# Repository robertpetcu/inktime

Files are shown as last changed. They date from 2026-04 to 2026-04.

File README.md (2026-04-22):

# InkTime - TSC

## Robert Cristian Petcu

# InkTime Smartwatch

InkTime is a smartwatch prototype built around the **nRF52840** SoC. The device features an **E-Paper display**, **BLE connectivity**, **battery charging and monitoring**, **motion sensing**, and **haptic feedback**, all integrated into a compact low-power wearable platform. The system is designed around a Li-Po battery, USB-C charging, an efficient 3.3V power stage, and a modular peripheral architecture.

---

## 1. Block Diagram

```text
+----------------------+
|      USB-C Port      |
+----------+-----------+
           |
           v
+----------------------+
|  Power / Charging IC |
|     BQ25180YBGR      |
+----------+-----------+
           |
           v
+----------------------+          +----------------------+
|    Li-Po Battery     |--------->|    3V3 Regulator    |
+----------------------+   VBAT   |      RT6160AWSC     |
                                  +----------+-----------+
                                             |
                                             v
                                   +----------------------+
                                   |     nRF52840 MCU     |
                                   |      MCU + BLE       |
                                   +---+----+----+---+----+
                                       |    |    |   |
                 USB ------------------+    |    |   +---------------- GPIO
                                       |    |    |                       |
                                       |    |    |                       +--> Buttons
                                       |    |    |
                                       |    |    +---------------- SWD
                                       |    |                            |
                                       |    |                            +--> SWD Debug
                                       |    |
                                       |    +---------------- I2C
                                       |                                 |
                                       |                                 +--> IMU (BMA421)
                                       |                                 |
                                       |                                 +--> Fuel Gauge (MAX17048G+T10)
                                       |                                 |
                                       |                                 +--> Haptic Driver (DRV2605YZFR)
                                       |                                                       |
                                       |                                                       +--> Haptic Motor
                                       |
                     SPI --------------+------------------------> E-Paper Display
                                       |                         (Display + E-Paper Drive)
                                       |
                     RF ---------------+------------------------> 2.4 GHz Antenna
                                                                 2450AT18B100E
                                                                
```

---

## 2. Bill of Materials (BOM)

### 2.1 Main Components

| Component | Designator(s) | Qty | Package | Purpose | JLC Parts | Datasheet |
|---|---|---:|---|---|---|---|
| nRF52840 | U1 | 1 | aQFN | Main MCU + BLE | [JLC Search](https://jlcpcb.com/parts/componentSearch?searchTxt=nRF52840) | [Nordic Product Page](https://www.nordicsemi.com/Products/nRF52840) |
| BQ25180YBGR | IC1 | 1 | BGA | Li-Po charging / power path | [JLC Search](https://jlcpcb.com/parts/componentSearch?searchTxt=BQ25180YBGR) | [TI Product Page](https://www.ti.com/product/BQ25180) |
| RT6160AWSC | IC9 | 1 | BGA | 3V3 regulator / DC-DC | [JLC Search](https://jlcpcb.com/parts/componentSearch?searchTxt=RT6160AWSC) | [Richtek Product Page](https://www.richtek.com/m/Products/Switching%20Regulators/Buck-Boost%20Converter/RT6160A?sc_lang=en) |
| BMA421 | IC3 | 1 | LGA | IMU sensor | [JLC Search](https://jlcpcb.com/parts/componentSearch?searchTxt=BMA421) | [Datasheet PDF](https://files.pine64.org/doc/datasheet/pinetime/BST-BMA421-FL000.pdf) |
| MAX17048G+T10 | U3 | 1 | SON / DFN | Fuel gauge | [JLC Search](https://jlcpcb.com/parts/componentSearch?searchTxt=MAX17048G%2BT10) | [Analog Devices Product Page](https://www.analog.com/en/products/max17048.html) |
| DRV2605YZFR | IC2 | 1 | DSBGA | Haptic driver | [JLC Search](https://jlcpcb.com/parts/componentSearch?searchTxt=DRV2605YZFR) | [TI Product Page](https://www.ti.com/product/DRV2605) |
| KH-TYPE-C-16P | J4 | 1 | SMD | USB-C connector | [JLC Search](https://jlcpcb.com/parts/componentSearch?searchTxt=KH-TYPE-C-16P) | [Datasheet PDF](https://datasheet.lcsc.com/lcsc/2404191039_Shenzhen-Kinghelm-Elec-KH-TYPE-C-16P_C709357.pdf) |
| 503480-2400 | J1 | 1 | FPC | E-paper display connector | [JLC Search](https://jlcpcb.com/parts/componentSearch?searchTxt=503480-2400) | [Molex Product Page](https://www.molex.com/en-us/products/part-detail/5034802400) |
| TC2030-IDC | J2 | 1 | Debug connector | SWD programming / debug | [JLC Search](https://jlcpcb.com/parts/componentSearch?searchTxt=TC2030-IDC) | [Tag-Connect Product Page](https://www.tag-connect.com/product/tc2030-idc-6-pin-tag-connect-plug-of-nails-spring-pin-cable-with-legs) |
| 2450AT18B100E | ANT1 | 1 | SMD antenna | 2.4 GHz antenna | [JLC Search](https://jlcpcb.com/parts/componentSearch?searchTxt=2450AT18B100E) | [Johanson Datasheet PDF](https://www.johansontechnology.com/docs/1187/2450AT18B100_X8XXogU.pdf) |
| 32 MHz crystal | X1 | 1 | 2016 | Main high-speed clock | [JLC Search](https://jlcpcb.com/parts/componentSearch?searchTxt=32MHz%202016) | [Search / vendor selection](https://jlcpcb.com/parts/componentSearch?searchTxt=32MHz%202016%20crystal) |
| 32.768 kHz crystal | X2 | 1 | 3215 | Low-power RTC clock | [JLC Search](https://jlcpcb.com/parts/componentSearch?searchTxt=32.768kHz%203215) | [Search / vendor selection](https://jlcpcb.com/parts/componentSearch?searchTxt=32.768kHz%203215%20crystal) |
| Buttons | SW_UP, SW_ENT, SW_DN | 3 | SMD | User input | [JLC Search](https://jlcpcb.com/parts/componentSearch?searchTxt=EVP-AKE31A) | [Panasonic Search](https://industry.panasonic.com/global/en/search?keyword=EVP-AKE31A) |
| USB ESD protection | D3 | 1 | SOT-23-6 | USB line protection | [JLC Search](https://jlcpcb.com/parts/componentSearch?searchTxt=USBLC6-2SC6Y) | [ST Product Page](https://www.st.com/en/protections-and-emi-filters/usblc6-2sc6y.html) |
| Schottky diodes | D2, D4, D5 | 3 | SMD | E-paper drive circuit | [JLC Search](https://jlcpcb.com/parts/componentSearch?searchTxt=MBR0530) | [onsemi Datasheet PDF](https://www.onsemi.com/download/data-sheet/pdf/mbr0530t1-d.pdf) |

---

## 3. Hardware Functionality Description

The InkTime smartwatch is built around the **nRF52840**, which acts as the main MCU and BLE controller. It manages the display, sensors, battery monitoring, haptic feedback, buttons, debugging, and RF communication.

### 3.1 Main MCU - nRF52840
The **nRF52840** is the central controller of the system. It was chosen for its:
- low power consumption
- BLE support
- SPI, I2C, USB, and SWD interfaces
- enough GPIOs for all peripherals

### 3.2 Power and Charging
The device is powered by a **Li-Po battery** and charged through **USB-C**. Charging and power-path management are handled by the **BQ25180YBGR**, while the **RT6160AWSC** generates the regulated **3.3V** supply for the system.

### 3.3 E-Paper Display
The display is connected through an **FPC connector** and controlled by the MCU over **SPI**. The display subsystem includes both the connector and the dedicated **e-paper drive circuit**.

### 3.4 IMU
Motion sensing is provided by the **BMA421**, connected over **I2C**. It is used for motion detection, gesture handling, and wake-up events.

### 3.5 Fuel Gauge
Battery monitoring is handled by the **MAX17048G+T10**, connected over **I2C**. It provides battery voltage and state-of-charge information to the MCU.

### 3.6 Haptic Driver
Haptic feedback is implemented using the **DRV2605YZFR**, also connected through **I2C**. It drives the vibration motor for notifications and user feedback.

### 3.7 Buttons
The device includes three buttons:
- **SW_UP**
- **SW_ENT**
- **SW_DN**

These are connected to GPIO pins and are used for user input and menu navigation.

### 3.8 SWD Debug
Programming and debugging are done through the **TC2030-IDC** SWD interface, which provides access to flashing and debugging during development.

### 3.9 RF Section
Wireless communication is handled by the nRF52840 through the **2450AT18B100E** 2.4 GHz antenna and its RF matching network.

---

## 4. nRF52840 Pin Usage

| Function | nRF52840 Pin | Description |
|---|---|---|
| EPD_CS | P0.05 | E-paper chip select |
| SDA | P0.06 | I2C data line |
| SCL | P0.07 | I2C clock line |
| IMU_INT1 | P0.08 | IMU interrupt 1 |
| IMU_INT2 | P1.08 | IMU interrupt 2 |
| Fuel Gauge ALERT | P0.10 | Battery alert signal |
| PMIC_INT | P0.11 | Charger / PMIC interrupt |
| HAPTIC_EN | P0.12 | Haptic control / enable |
| SW_UP | P0.13 | Button input |
| SW_ENT | P0.14 | Button input |
| SW_DN | P1.02 | Button input |
| SWDIO | SWDIO | Debug data |
| SWDCLK | SWDCLK | Debug clock |
| RESET | P0.18 / RESET | System reset |
| USB D+ / D- | Dedicated USB pins | USB interface |
| RF ANT | ANT | Antenna connection |

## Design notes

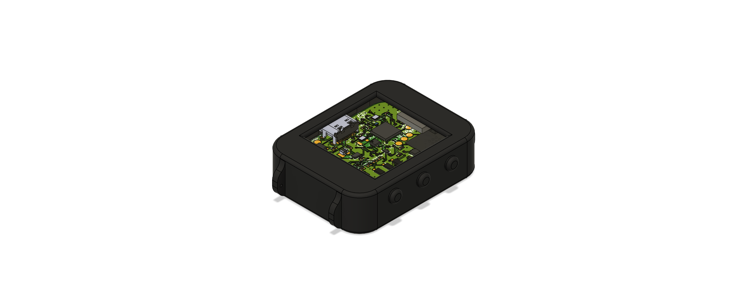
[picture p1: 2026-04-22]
Images/WearAwareNewCase.png

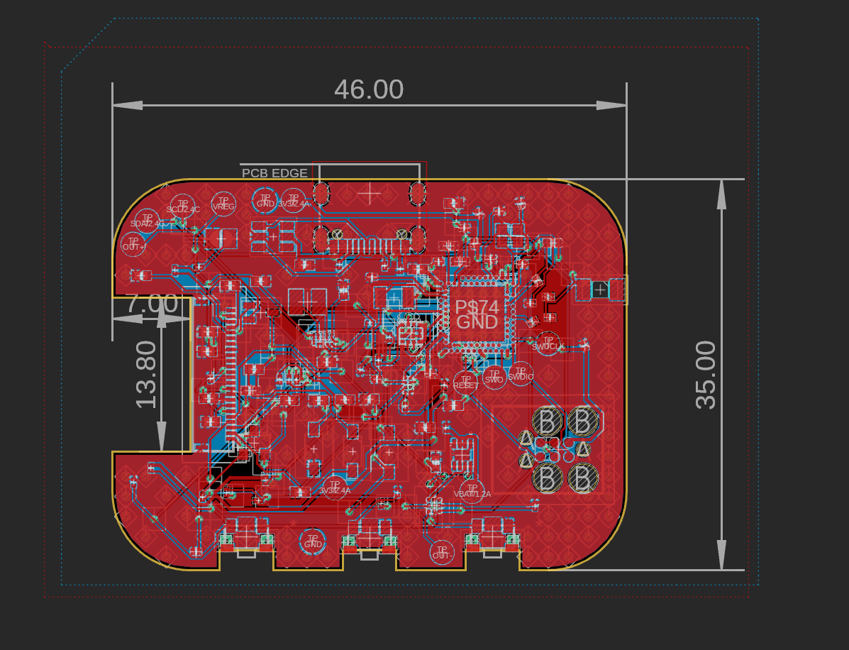
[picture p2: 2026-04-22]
Images/2dpcb.png

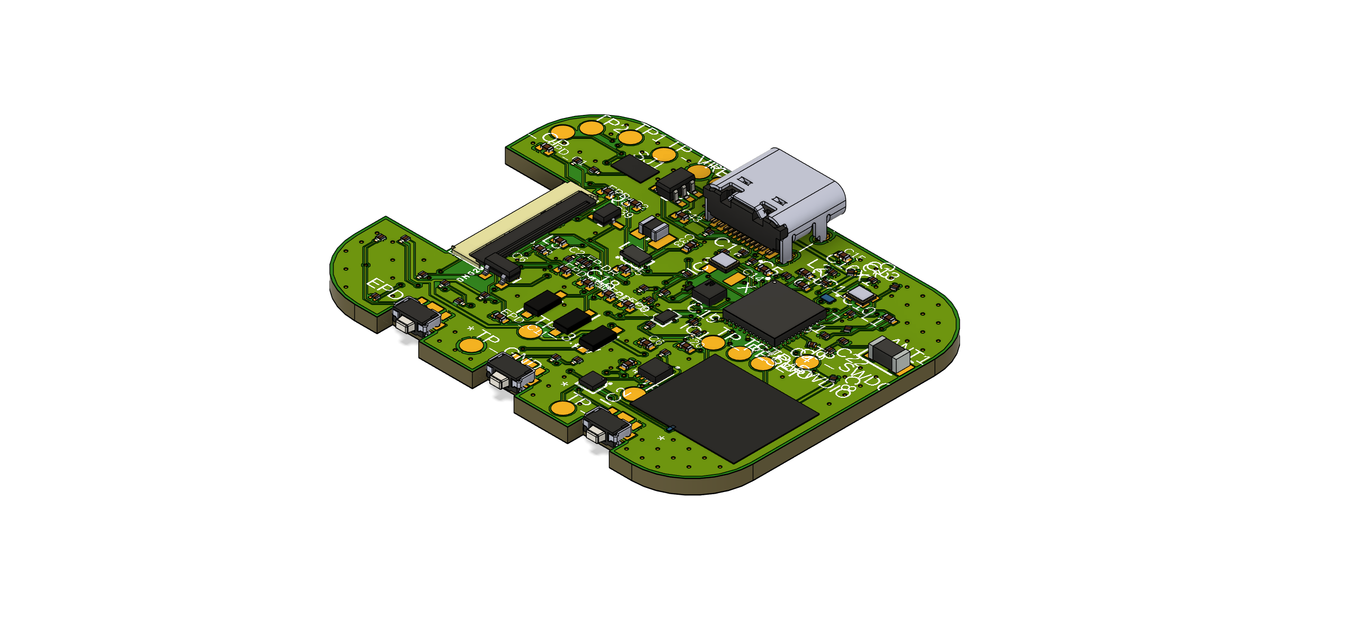
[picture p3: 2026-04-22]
Images/PCB3d.png

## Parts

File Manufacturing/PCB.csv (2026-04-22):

Qty | Value | Device | Package | Parts | Description | ARROW_PART_NUMBER | ARROW_PRICE-STOCK | AVAILABILITY | CHECK_PRICES | COPYRIGHT | DESCRIPTION | DIGI-KEY_PART_NUMBER_1 | DIGI-KEY_PART_NUMBER_2 | DIGI-KEY_PART_NUMBER_3 | HEIGHT | JLCPCB | MANUFACTURER_NAME | MANUFACTURER_PART_NUMBER | MF | MOUSER_PART_NUMBER | MOUSER_PRICE-STOCK | MP | PACKAGE | POPULARITY | PRICE | PROD_ID | PURCHASE-URL | SNAPEDA_LINK | TP_SIGNAL_NAME | VALUE
1 |  | ESP32_C6_LIBRARY_7_JUMPER_SJ | ESP32_C6_LIBRARY_7_JUMPER_SJ | SJ1 | SMD solder JUMPER |  |  |  |  |  |  |  |  |  |  |  |  |  |  |  |  |  |  | 3
3 | 0 | CPF0201D7K68C1_CPF0201D7K68C1 | CPF0201D7K68C1_0201 | R2, R3, R4 | 7.68k 0201 Thin Film Surface Mount Fixed Resistor +/-0.5% 0.031W CPF0201D7K68C1
4 | 0.1uF | GRM011R60J152KE01L_1_GRM011R60J152KE01L | GRM011R60J152KE01L_1_0201 | C23, C27, C34, C42 | Check availability
1 | 0.1uF/50V | NORDIC_NRF_3_CAPACITOR_0201_L | NORDIC_NRF_3_RESC0201_L | EPD_C5 | Generic chip capacitor
1 | 0.47 | CPF0201D7K68C1_CPF0201D7K68C1 | CPF0201D7K68C1_0201 | R1_EP_DR | 7.68k 0201 Thin Film Surface Mount Fixed Resistor +/-0.5% 0.031W CPF0201D7K68C1
1 | 1.0µF | PERFECT_0402_CAP_0402 | PERFECT_0402_0402 | C15 | 0402 (1005 Metric)
5 | 100nF | NORDIC_NRF_3_CAPACITOR_0201_L | NORDIC_NRF_3_RESC0201_L | C5, C7, C8, C12, C19 | Generic chip capacitor
1 | 100pF | NORDIC_NRF_3_CAPACITOR_0201_L | NORDIC_NRF_3_RESC0201_L | C11 | Generic chip capacitor
3 | 10K | CPF0201D7K68C1_CPF0201D7K68C1 | CPF0201D7K68C1_0201 | R2_EP_DR, R9, R_PWR_EPD | 7.68k 0201 Thin Film Surface Mount Fixed Resistor +/-0.5% 0.031W CPF0201D7K68C1
3 | 10k | CPF0201D7K68C1_CPF0201D7K68C1 | CPF0201D7K68C1_0201 | R5, R7, R8 | 7.68k 0201 Thin Film Surface Mount Fixed Resistor +/-0.5% 0.031W CPF0201D7K68C1
3 | 10uF | PERFECT_0402_CAP_0402 | PERFECT_0402_0402 | C1-EP-DR, C24, C39 | 0402 (1005 Metric)
1 | 10µH | NORDIC_NRF_2_INDUCTOR_0402_L | NORDIC_NRF_2_RESC0402_L | L2 | Generic chip inductor
4 | 12pF | NORDIC_NRF_3_CAPACITOR_0201_L | NORDIC_NRF_3_RESC0201_L | C1, C2, C17, C18 | Generic chip capacitor
1 | 15nH | NORDIC_NRF_2_INDUCTOR_0402_L | NORDIC_NRF_2_RESC0402_L | L3 | Generic chip inductor
2 | 1pF | NORDIC_NRF_3_CAPACITOR_0201_L | NORDIC_NRF_3_RESC0201_L | C3, C4 | Generic chip capacitor
6 | 1uF | GRM011R60J152KE01L_1_GRM011R60J152KE01L | GRM011R60J152KE01L_1_0201 | C29, C30, C31, C32, C37, C38 | Check availability
9 | 1uF/50V | PERFECT_0402_CAP_0402 | PERFECT_0402_0402 | EPD_C1, EPD_C2, EPD_C6, EPD_C7, EPD_C8, EPD_C9, EPD_C10, EPD_C11, EPD_C12 | 0402 (1005 Metric)
1 | 2.2 | CPF0201D7K68C1_CPF0201D7K68C1 | CPF0201D7K68C1_0201 | R_TYPE_SEL | 7.68k 0201 Thin Film Surface Mount Fixed Resistor +/-0.5% 0.031W CPF0201D7K68C1
3 | 2025-10-22_07-23-44_LIBRARY_EVP-AKE31ASW_EVP-AKE31A_PAN | 2025-10-22_07-23-44_LIBRARY_EVP-AKE31ASW_EVP-AKE31A_PAN | 2025-10-22_07-23-44_LIBRARY_SW_EVP-AKE31A_PAN | SW_DN, SW_ENT, SW_UP |  |  |  |  |  | Copyright (C) 2025 Ultra Librarian. All rights reserved. |  | P123437TR-ND | P123437CT-ND | P123437DKR-ND |  |  | Panasonic | EVP-AKE31A
1 | 20V/4.2A/52mO/1.4W | ESP32_C6_LIBRARY_4_ESP32_WROVER_SPARKFUN-DISCRETESEMI_MOSFET_PCH-DMG2305UX-7 | ESP32_C6_LIBRARY_4_ESP32_C6_LIBRARY_4_ESP32_C6_LIBRARY_4_ESP32_C6_LIBRARY_4_ESP32_WROVER_SPARKFUN-DISCRETESEMI_SOT23-3 | DMG2305UX-7 | P-channel MOSFETs |  |  |  |  |  |  |  |  |  |  |  |  |  |  |  |  |  |  |  |  | TRAN-14388 |  |  |  | 20V/4.2A/52mO/1.4W
2 | 22uF | PERFECT_0402_CAP_0402 | PERFECT_0402_0402 | C25, C33 | 0402 (1005 Metric)
1 | 2450AT18B100E | 2450AT18B100E_2450AT18B100E | 2450AT18B100E_ANTC3216X140N | ANT1 | Antennas 2.45GHz ANTENNA | 2450AT18B100E | https://www.arrow.com/en/products/2450at18b100e/johanson-dielectrics?utm_currency=USD&region=nac |  |  |  | Antennas 2.45GHz ANTENNA |  |  |  | 1.4mm |  | JOHANSON TECHNOLOGY | 2450AT18B100E |  | 609-2450AT18B100E | https://www.mouser.co.uk/ProductDetail/Johanson-Technology/2450AT18B100E?qs=yCnrNFeXz%252Bh5MFsFIXGZGA%3D%3D
1 | 3.9nH | NORDIC_NRF_2_INDUCTOR_0402_L | NORDIC_NRF_2_RESC0402_L | L1 | Generic chip inductor
1 | 32.768kHz | NORDIC_NRF_1_XTAL_32KHZ | NORDIC_NRF_1_XTAL_3215_N | X2
1 | 32MHz | NORDIC_NRF_XTAL_32MHZ | NORDIC_NRF_BT-XTAL_2016_N | X1
2 | 3K3 | CPF0201D7K68C1_CPF0201D7K68C1 | CPF0201D7K68C1_0201 | R17, R18 | 7.68k 0201 Thin Film Surface Mount Fixed Resistor +/-0.5% 0.031W CPF0201D7K68C1
1 | 4.7uF | PERFECT_0402_CAP_0402 | PERFECT_0402_0402 | C43 | 0402 (1005 Metric)
1 | 4.7uF/25V | PERFECT_0402_CAP_0402 | PERFECT_0402_0402 | C2-EP-DR | 0402 (1005 Metric)
4 | 4.7µF | PERFECT_0402_CAP_0402 | PERFECT_0402_0402 | C6, C14, C20, C21 | 0402 (1005 Metric)
1 | 47nF | NORDIC_NRF_3_CAPACITOR_0201_L | NORDIC_NRF_3_RESC0201_L | C16 | Generic chip capacitor
1 | 503480-2400 | 503480-2400_503480-2400 | 503480-2400_5034802400 | J1 | FFC & FPC Connectors 0.5mm FPC RA SMT Dual Contact 24Ckt |  |  |  |  |  | FFC & FPC Connectors 0.5mm FPC RA SMT Dual Contact 24Ckt |  |  |  | 1.87mm |  | Molex | 503480-2400 |  | 538-503480-2400 | https://www.mouser.co.uk/ProductDetail/Molex/503480-2400?qs=OAhjpuo3Vu7efIoxFh9AOw%3D%3D
2 | 5K1 | CPF0201D7K68C1_CPF0201D7K68C1 | CPF0201D7K68C1_0201 | R1_USB, R2_USB | 7.68k 0201 Thin Film Surface Mount Fixed Resistor +/-0.5% 0.031W CPF0201D7K68C1
1 | 68uH | NORDIC_NRF_2_INDUCTOR_0402_L | NORDIC_NRF_2_RESC0402_L | L5 | Generic chip inductor
1 | 820pF | NORDIC_NRF_3_CAPACITOR_0201_L | NORDIC_NRF_3_RESC0201_L | C9 | Generic chip capacitor
1 | BMA421 | BMA423_BMA423 | BMA423_BMA423 | IC3 | Accelerometers Triaxial low-g 12bit Acceleration Sensor | BMA423 | https://www.arrow.com/en/products/bma423/bosch |  |  |  | Accelerometers Triaxial low-g 12bit Acceleration Sensor |  |  |  | 1mm |  | BOSCH | BMA423 |  | 262-BMA423 | https://www.mouser.co.uk/ProductDetail/Bosch-Sensortec/BMA423?qs=HXFqYaX1Q2xC%252BSgeGoX3mg%3D%3D
1 | BQ25180YBGR | BQ25180YBGR_BQ25180YBGR | BQ25180YBGR_BGA8C40P2X4_100X155X50 | IC1 | Charger IC Lithium Ion/Polymer, Lithium Iron Phosphate 8-DSBGA (1.6x1.1) | BQ25180YBGR | https://www.arrow.com/en/products/bq25180ybgr/texas-instruments?utm_currency=USD&region=nac |  |  |  | Charger IC Lithium Ion/Polymer | Lithium Iron Phosphate 8-DSBGA (1.6x1.1) |  |  |  | 0.5mm |  | Texas Instruments | BQ25180YBGR |  | 595-BQ25180YBGR | https://www.mouser.co.uk/ProductDetail/Texas-Instruments/BQ25180YBGR?qs=doiCPypUmgEWjAK%252BJAX6Tw%3D%3D
1 | DRV2605YZFR | DRV2605YZFR_DRV2605YZFR | DRV2605YZFR_BGA9C50P3X3_144X144X62 | IC2 | Haptic Driver for ERM/LRA with Built-In Library and Smart Loop Architecture | DRV2605YZFR | https://www.arrow.com/en/products/drv2605yzfr/texas-instruments?region=nac |  |  |  | Haptic Driver for ERM/LRA with Built-In Library and Smart Loop Architecture |  |  |  | 0.625mm |  | Texas Instruments | DRV2605YZFR
1 | FTC252012SR47MBCA | MLP2016SR47MT0S1_FTC252012SR47MBCA | MLP2016SR47MT0S1_INDC2016X100N | L7 | SMD / SMT Inductors (Coils), L=0.47?H, L x W x T : |  |  |  |  |  | SMD / SMT Inductors (Coils) | L=0.47?H | L x W x T : |  |  |  | 1mm | https://jlcpcb.com/partdetail/6763488-FTC252012SR47MBCA/C5832368 | TDK | FTC252012SR47MBCA
14 | HECTOR_WATCH_1_TPTP20R | HECTOR_WATCH_1_TPTP20R | HECTOR_WATCH_1_TP20R | TP1, TP2, TP_3.3V, TP_3V3, TP_BAT_GND, TP_GND, TP_ON, TP_OP, TP_RESET, TP_SWDCLK, TP_SWDIO, TP_SWO, TP_VBAT, TP_VREG | Test pad |  |  |  |  |  |  |  |  |  |  |  |  |  |  |  |  |  |  | 2
1 | KH-TYPE-C-16P | KH-TYPE-C-16P_KH-TYPE-C-16P | KH-TYPE-C-16P_KINGHELM_KH-TYPE-C-16P | J4 | Check availability |  |  | Not in stock | https://www.snapeda.com/parts/KH-TYPE-C-16P/Kinghelm/view-part/?ref=eda |  |  |  |  |  |  |  |  |  | kinghelm |  |  | KH-TYPE-C-16P | None |  | None |  |  | https://www.snapeda.com/parts/KH-TYPE-C-16P/Kinghelm/view-part/?ref=snap
1 | MAX17048G+T10 | ESP32_C6_LIBRARY_MAX17048G+T10 | ESP32_C6_LIBRARY_SON50P200X200X80-9N | U3 | Check availability |  |  | In Stock | https://www.snapeda.com/parts/MAX17048G+T10/Analog+Devices/view-part/?ref=eda |  | 3µA 1-Cell/2-Cell Fuel Gauge with ModelGauge |  |  |  |  |  |  |  | Analog Devices |  |  | MAX17048G+T10 | TDFN-8 Maxim |  | None |  | https://www.snapeda.com/api/url_track_click_mouser/?unipart_id=329239&manufacturer=Analog Devices&part_name=MAX17048G+T10&search_term=None | https://www.snapeda.com/parts/MAX17048G+T10/Analog+Devices/view-part/?ref=snap
3 | MBR0530 | ESP32_C6_LIBRARY_5_MBR0530 | ESP32_C6_LIBRARY_5_SOD3716X135N | D2, D4, D5 | ON SEMICONDUCTOR - MBR0530 - DIODE, SCHOTTKY, 0.5A, 30V, SOD-123 |  |  | In Stock | https://www.snapeda.com/parts/MBR0530/Onsemi/view-part/?ref=eda |  | Diode Schottky 30 V 500mA Surface Mount SOD-123 |  |  |  |  |  |  |  | ON Semiconductor |  |  | MBR0530 | SOD-123-2 ON Semiconductor |  | None |  | https://www.snapeda.com/api/url_track_click_mouser/?unipart_id=179458&manufacturer=ON Semiconductor&part_name=MBR0530&search_term=None | https://www.snapeda.com/parts/MBR0530/Onsemi/view-part/?ref=snap
1 | N.C | NORDIC_NRF_3_CAPACITOR_0201_L | NORDIC_NRF_3_RESC0201_L | C10 | Generic chip capacitor
2 | N.C. | NORDIC_NRF_3_CAPACITOR_0201_L | NORDIC_NRF_3_RESC0201_L | C13, C22 | Generic chip capacitor
1 | NRF52840_QF | NORDIC_NRF_4_NRF52840_QF | NORDIC_NRF_4_AQFN50P700X700X85_HS-74N | U1 | nRF52840
1 | RT6160AWSC | RT6160AWSC_RT6160AWSC | RT6160AWSC_BGA15C40P3X5_140X230X60 | IC9 | Buck-Boost Regulator Positive Output Step-Up/Step-Down I2C DC-DC Controller IC 15-WL-CSP (BSC) (1.4x2.3) |  |  |  |  |  | Buck-Boost Regulator Positive Output Step-Up/Step-Down I2C DC-DC Controller IC 15-WL-CSP (BSC) (1.4x2.3) |  |  |  | 0.6mm |  | RICHTEK | RT6160AWSC |  | 835-RT6160AWSC | https://www.mouser.co.uk/ProductDetail/Richtek/RT6160AWSC?qs=amGC7iS6iy%2FLd9PSoixZXQ%3D%3D
1 | SI1308EDL-T1-GE3 | ESP32_C6_LIBRARY_6_SI1308EDL-T1-GE3 | ESP32_C6_LIBRARY_6_SOT65P210X110-3N | Q3 | MOSFET N-Ch 30V 1.5A TrenchFET SC70 Vishay Si1308EDL-T1-GE3 N-channel MOSFET Transistor, 1.5 A, 30 V, 3-Pin SC-70 |  |  | In Stock | https://www.snapeda.com/parts/SI1308EDL-T1-GE3/Vishay+Siliconix/view-part/?ref=eda |  | Si1308EDL-T1-GE3 N-channel MOSFET Transistor | 1.5 A | 30 V | 3-Pin SC-70 | Siliconix / Vishay SI1308EDL-T1-GE3 |  |  |  |  |  |  |  | Vishay Siliconix |  |  | SI1308EDL-T1-GE3 | SOT-323 Vishay Semiconductor |  | None |  | https://www.snapeda.com/api/url_track_click_mouser/?unipart_id=274603&manufacturer=Vishay Siliconix&part_name=SI1308EDL-T1-GE3&search_term=None
1 | TC2030-IDC | TC2030-IDC_TC2030-IDC | TC2030-IDC_TC2030IDC | J2 | CABLE ADAPTER 6 POS |  |  |  |  |  | CABLE ADAPTER 6 POS |  |  |  | 19mm |  | Tag Connect | TC2030-IDC
1 | USBLC6-2SC6Y | ESP32_C6_LIBRARY_3_USBLC6-2SC6Y | ESP32_C6_LIBRARY_3_SOT95P280X145-6N | D3 | Low Cap. ESD Protection Auto SOT-23-6 STMicroelectronics USBLC6-2SC6Y, Dual Uni-Directional TVS Diode Array, 6-Pin SOT-23 |  |  | In Stock | https://www.snapeda.com/parts/USBLC6-2SC6Y/STMicroelectronics/view-part/?ref=eda |  | 17V Clamp 5A (8/20µs) Ipp Tvs Diode Surface Mount SOT-23-6 |  |  |  |  |  |  |  | STMicroelectronics |  |  | USBLC6-2SC6Y | SOT-23-6 STMicroelectronics |  | None |  |  | https://www.snapeda.com/parts/USBLC6-2SC6Y/STMicroelectronics/view-part/?ref=snap

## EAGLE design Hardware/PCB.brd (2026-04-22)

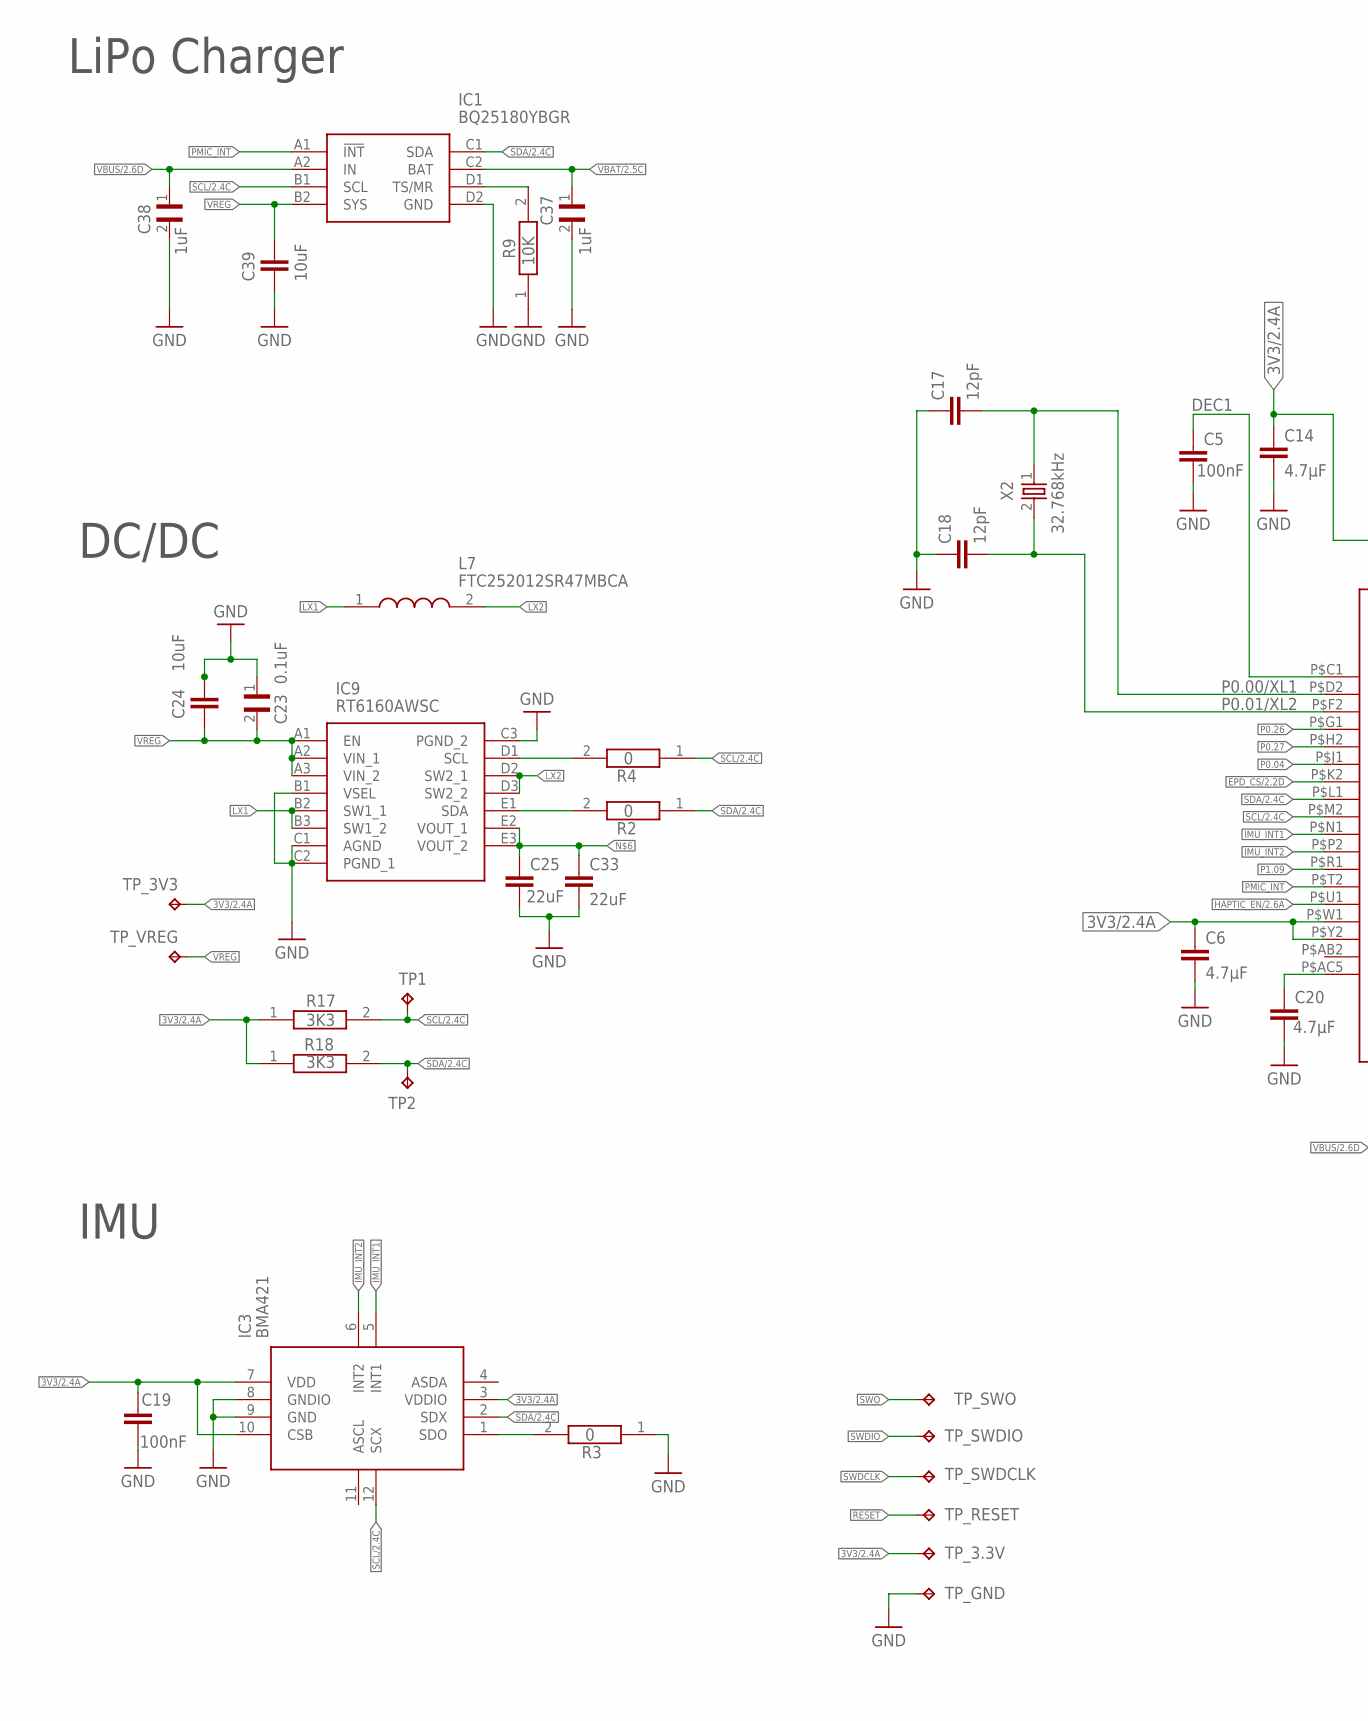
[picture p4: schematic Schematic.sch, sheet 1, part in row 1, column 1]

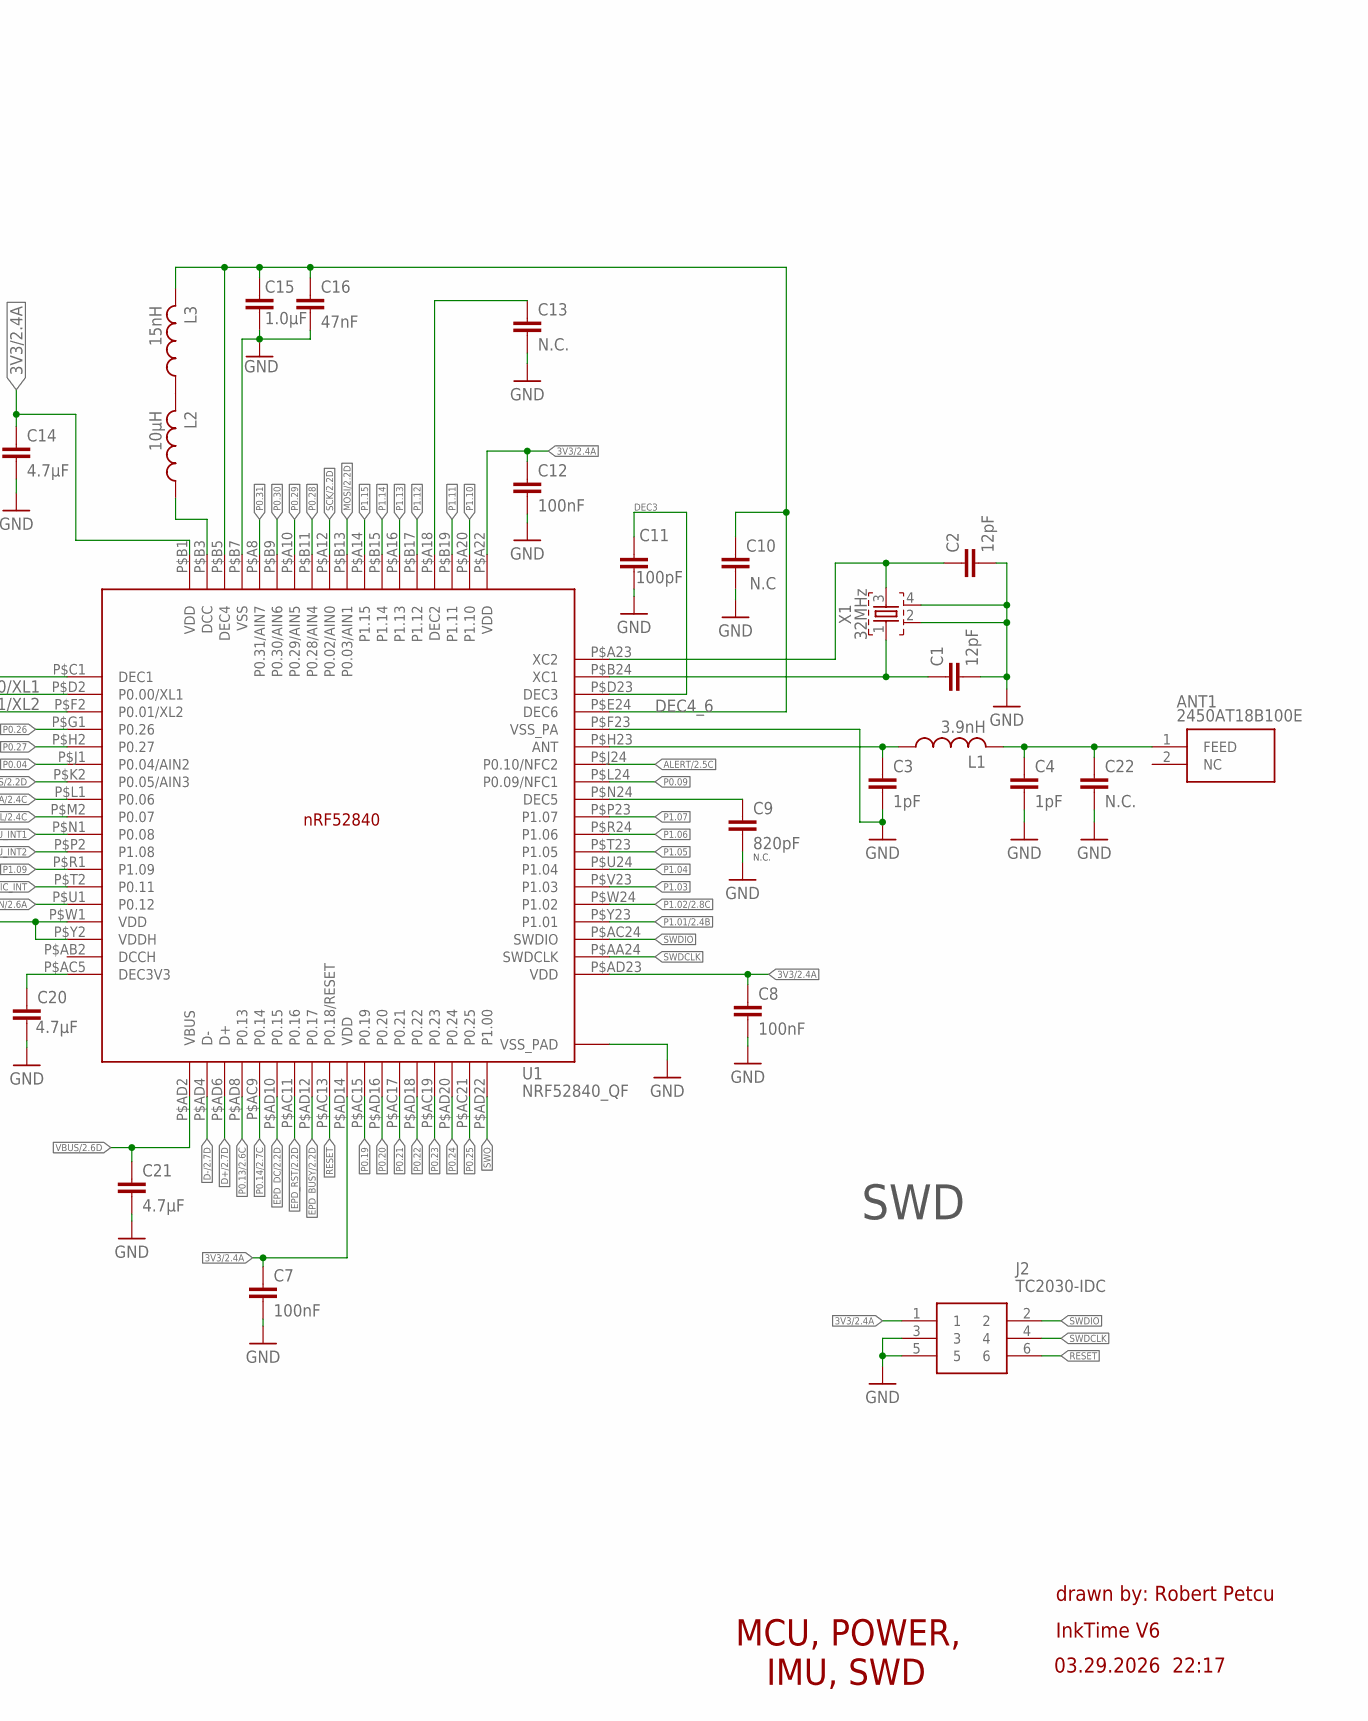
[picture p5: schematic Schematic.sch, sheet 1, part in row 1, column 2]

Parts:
ANT1: 2450AT18B100E; 2450AT18B100E_ANTC3216X140N
C1, C2, C17, C18: 12pF; NORDIC_NRF_3_RESC0201_L
C3, C4: 1pF; NORDIC_NRF_3_RESC0201_L
C5, C7, C8, C12, C19: 100nF; NORDIC_NRF_3_RESC0201_L
C6, C14, C20, C21: 4.7µF; PERFECT_0402_0402
C9: 820pF; NORDIC_NRF_3_RESC0201_L
C10: N.C; NORDIC_NRF_3_RESC0201_L
C11: 100pF; NORDIC_NRF_3_RESC0201_L
C13, C22: N.C.; NORDIC_NRF_3_RESC0201_L
C15: 1.0µF; PERFECT_0402_0402
C16: 47nF; NORDIC_NRF_3_RESC0201_L
C23: 0.1uF; GRM011R60J152KE01L_1_0201
C24, C39: 10uF; PERFECT_0402_0402
C25, C33: 22uF; PERFECT_0402_0402
C37, C38: 1uF; GRM011R60J152KE01L_1_0201
IC1: BQ25180YBGR; BQ25180YBGR_BGA8C40P2X4_100X155X50
IC3: BMA421; BMA423_BMA423
IC9: RT6160AWSC; RT6160AWSC_BGA15C40P3X5_140X230X60
J2: TC2030-IDC; TC2030-IDC_TC2030IDC
L1: 3.9nH; NORDIC_NRF_2_RESC0402_L
L2: 10µH; NORDIC_NRF_2_RESC0402_L
L3: 15nH; NORDIC_NRF_2_RESC0402_L
L7: FTC252012SR47MBCA; MLP2016SR47MT0S1_INDC2016X100N
R2, R3, R4: 0; CPF0201D7K68C1_0201
R9: 10K; CPF0201D7K68C1_0201
R17, R18: 3K3; CPF0201D7K68C1_0201
TP1, TP2: HECTOR_WATCH_1_TPTP20R; HECTOR_WATCH_1_TP20R
TP_3.3V, TP_3V3: HECTOR_WATCH_1_TPTP20R; HECTOR_WATCH_1_TP20R
TP_GND: HECTOR_WATCH_1_TPTP20R; HECTOR_WATCH_1_TP20R
TP_RESET: HECTOR_WATCH_1_TPTP20R; HECTOR_WATCH_1_TP20R
TP_SWDCLK: HECTOR_WATCH_1_TPTP20R; HECTOR_WATCH_1_TP20R
TP_SWDIO: HECTOR_WATCH_1_TPTP20R; HECTOR_WATCH_1_TP20R
TP_SWO: HECTOR_WATCH_1_TPTP20R; HECTOR_WATCH_1_TP20R
TP_VREG: HECTOR_WATCH_1_TPTP20R; HECTOR_WATCH_1_TP20R
U1: NRF52840_QF; NORDIC_NRF_4_AQFN50P700X700X85_HS-74N
X1: 32MHz; NORDIC_NRF_BT-XTAL_2016_N
X2: 32.768kHz; NORDIC_NRF_1_XTAL_3215_N

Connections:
3V3/2.4A: C6.1, C7.1, C8.1, C12.1, C14.1, C19.1, IC3.3 (VDDIO), IC3.7 (VDD), IC3.10 (CSB), J2.1, R17.1, R18.1, TP_3.3V.TP, TP_3V3.TP, U1.P$A22 (VDD), U1.P$AD14 (VDD), U1.P$AD23 (VDD), U1.P$B1 (VDD), U1.P$W1 (VDD), U1.P$Y2 (VDDH)
ALERT/2.5C: U1.P$J24 (P0.10/NFC2)
D+/2.7D: U1.P$AD6 (D+)
D-/2.7D: U1.P$AD4 (D-)
DEC1: C5.1, U1.P$C1 (DEC1)
DEC3: C11.1, U1.P$D23 (DEC3)
DEC4_6: C10.1, C15.1, C16.1, L3.2, U1.P$B5 (DEC4), U1.P$E24 (DEC6)
EPD_BUSY/2.2D: U1.P$AD12 (P0.17)
EPD_CS/2.2D: U1.P$K2 (P0.05/AIN3)
EPD_DC/2.2D: U1.P$AD10 (P0.15)
EPD_RST/2.2D: U1.P$AC11 (P0.16)
GND: C1.2, C2.2, C3.2, C4.2, C5.2, C6.2, C7.2, C8.2, C9.2, C10.2, C11.2, C12.2, C13.2, C14.2, C15.2, C16.2, C17.1, C18.1, C19.2, C20.2, C21.2, C22.2, C23.1, C24.1, C25.2, C33.2, C37.2, C38.2, C39.2, IC1.D2 (GND), IC3.8 (GNDIO), IC3.9 (GND), IC9.B1 (VSEL), IC9.C1 (AGND), IC9.C2 (PGND_1), IC9.C3 (PGND_2), J2.3, J2.5, R3.1, R9.1, TP_GND.TP, U1.P$74 (VSS_PAD), U1.P$75 (VSS_PAD), U1.P$76 (VSS_PAD), U1.P$77 (VSS_PAD), U1.P$78 (VSS_PAD), U1.P$79 (VSS_PAD), U1.P$80 (VSS_PAD), U1.P$81 (VSS_PAD), U1.P$82 (VSS_PAD), U1.P$83 (VSS_PAD), U1.P$84 (VSS_PAD), U1.P$85 (VSS_PAD), U1.P$86 (VSS_PAD), U1.P$87 (VSS_PAD), U1.P$88 (VSS_PAD), U1.P$89 (VSS_PAD), U1.P$90 (VSS_PAD), U1.P$B7 (VSS), U1.P$F23 (VSS_PA), X1.2, X1.4; also elsewhere on the board
HAPTIC_EN/2.6A: U1.P$U1 (P0.12)
IMU_INT1: IC3.5 (INT1), U1.P$N1 (P0.08)
IMU_INT2: IC3.6 (INT2), U1.P$P2 (P1.08)
LX1: IC9.B2 (SW1_1), IC9.B3 (SW1_2), L7.1
LX2: IC9.D2 (SW2_1), IC9.D3 (SW2_2), L7.2
MOSI/2.2D: U1.P$B13 (P0.03/AIN1)
unnamed: IC9.D1 (SCL), R4.2
unnamed: IC9.E1 (SDA), R2.2
unnamed: IC1.D1 (TS/MR), R9.2
unnamed: C25.1, C33.1, IC9.E2 (VOUT_1), IC9.E3 (VOUT_2)
unnamed: L2.1, U1.P$B3 (DCC)
unnamed: C20.1, U1.P$AC5 (DEC3V3)
unnamed: IC3.1 (SDO), R3.2
unnamed: L2.2, L3.1
unnamed: C2.1, U1.P$A23 (XC2), X1.3
unnamed: C13.1, U1.P$A18 (DEC2)
unnamed: C9.1, U1.P$N24 (DEC5)
unnamed: C1.1, U1.P$B24 (XC1), X1.1
unnamed: C3.1, L1.1, U1.P$H23 (ANT)
unnamed: ANT1.1 (FEED), C4.1, C22.1, L1.2
P0.00/XL1: C17.2, U1.P$D2 (P0.00/XL1), X2.1
P0.01/XL2: C18.2, U1.P$F2 (P0.01/XL2), X2.2
P0.04: U1.P$J1 (P0.04/AIN2)
P0.09: U1.P$L24 (P0.09/NFC1)
P0.13/2.6C: U1.P$AD8 (P0.13)
P0.14/2.7C: U1.P$AC9 (P0.14)
P0.19: U1.P$AC15 (P0.19)
P0.20: U1.P$AD16 (P0.20)
P0.21: U1.P$AC17 (P0.21)
P0.22: U1.P$AD18 (P0.22)
P0.23: U1.P$AC19 (P0.23)
P0.24: U1.P$AD20 (P0.24)
P0.25: U1.P$AC21 (P0.25)
P0.26: U1.P$G1 (P0.26)
P0.27: U1.P$H2 (P0.27)
P0.28: U1.P$B11 (P0.28/AIN4)
P0.29: U1.P$A10 (P0.29/AIN5)
P0.30: U1.P$B9 (P0.30/AIN6)
P0.31: U1.P$A8 (P0.31/AIN7)
P1.01/2.4B: U1.P$Y23 (P1.01)
P1.02/2.8C: U1.P$W24 (P1.02)
P1.03: U1.P$V23 (P1.03)
P1.04: U1.P$U24 (P1.04)
P1.05: U1.P$T23 (P1.05)
P1.06: U1.P$R24 (P1.06)
P1.07: U1.P$P23 (P1.07)
P1.09: U1.P$R1 (P1.09)
P1.10: U1.P$A20 (P1.10)
P1.11: U1.P$B19 (P1.11)
P1.12: U1.P$B17 (P1.12)
P1.13: U1.P$A16 (P1.13)
P1.14: U1.P$B15 (P1.14)
P1.15: U1.P$A14 (P1.15)
PMIC_INT: IC1.A1 (!INT), U1.P$T2 (P0.11)
RESET: J2.6, TP_RESET.TP, U1.P$AC13 (P0.18/RESET)
SCK/2.2D: U1.P$A12 (P0.02/AIN0)
SCL/2.4C: IC1.B1 (SCL), IC3.12 (SCX), R4.1, R17.2, TP1.TP, U1.P$M2 (P0.07)
SDA/2.4C: IC1.C1 (SDA), IC3.2 (SDX), R2.1, R18.2, TP2.TP, U1.P$L1 (P0.06)
SWDCLK: J2.4, TP_SWDCLK.TP, U1.P$AA24 (SWDCLK)
SWDIO: J2.2, TP_SWDIO.TP, U1.P$AC24 (SWDIO)
SWO: TP_SWO.TP, U1.P$AD22 (P1.00)
VBAT/2.5C: C37.1, IC1.C2 (BAT)
VBUS/2.6D: C21.1, C38.1, IC1.A2 (IN), U1.P$AD2 (VBUS)
VREG: C23.2, C24.2, C39.1, IC1.B2 (SYS), IC9.A1 (EN), IC9.A2 (VIN_1), IC9.A3 (VIN_2), TP_VREG.TP

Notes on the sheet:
N.C.
LiPo Charger
DC/DC
IMU
SWD
MCU, POWER, IMU, SWD
drawn by: Robert Petcu
InkTime V6
03.29.2026 22:17

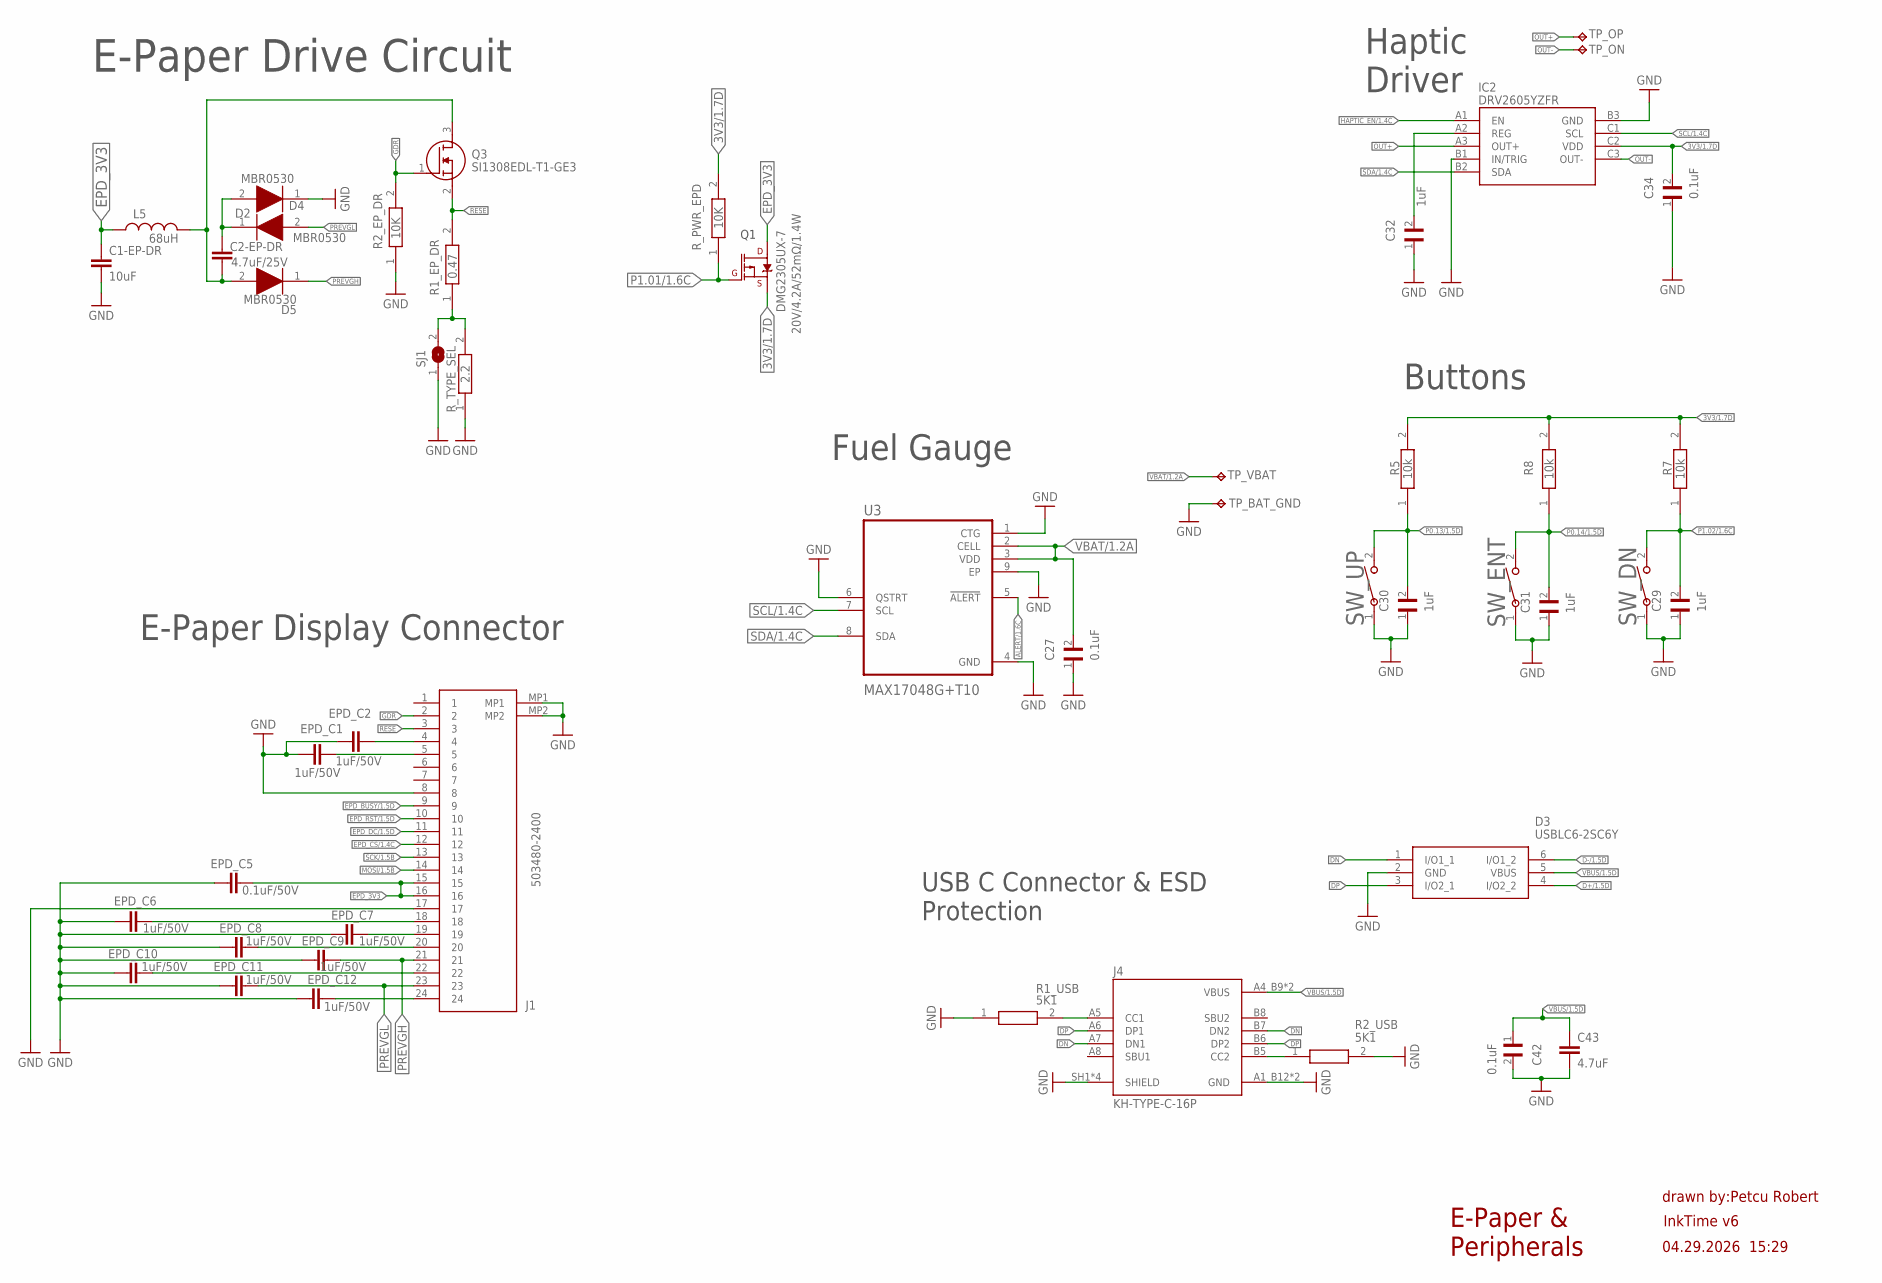
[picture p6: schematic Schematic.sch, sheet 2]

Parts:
C1-EP-DR: 10uF; PERFECT_0402_0402
C2-EP-DR: 4.7uF/25V; PERFECT_0402_0402
C27, C34, C42: 0.1uF; GRM011R60J152KE01L_1_0201
C29, C30, C31, C32: 1uF; GRM011R60J152KE01L_1_0201
C43: 4.7uF; PERFECT_0402_0402
D2, D4, D5: MBR0530; ESP32_C6_LIBRARY_5_SOD3716X135N
D3: USBLC6-2SC6Y; ESP32_C6_LIBRARY_3_SOT95P280X145-6N
DMG2305UX-7: 20V/4.2A/52mΩ/1.4W; ESP32_C6_LIBRARY_4_ESP32_C6_LIBRARY_4_ESP32_C6_LIBRARY_4_ES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
EPD_C1, EPD_C2, EPD_C6, EPD_C7, EPD_C8, EPD_C9, EPD_C10, EPD_C11, EPD_C12: 1uF/50V; PERFECT_0402_0402
EPD_C5: 0.1uF/50V; NORDIC_NRF_3_RESC0201_L
IC2: DRV2605YZFR; DRV2605YZFR_BGA9C50P3X3_144X144X62
J1: 503480-2400; 503480-2400_5034802400
J4: KH-TYPE-C-16P; KH-TYPE-C-16P_KINGHELM_KH-TYPE-C-16P
L5: 68uH; NORDIC_NRF_2_RESC0402_L
Q3: SI1308EDL-T1-GE3; ESP32_C6_LIBRARY_6_SOT65P210X110-3N
R1_EP_DR: 0.47; CPF0201D7K68C1_0201
R1_USB, R2_USB: 5K1; CPF0201D7K68C1_0201
R2_EP_DR: 10K; CPF0201D7K68C1_0201
R5, R7, R8: 10k; CPF0201D7K68C1_0201
R_PWR_EPD: 10K; CPF0201D7K68C1_0201
R_TYPE_SEL: 2.2; CPF0201D7K68C1_0201
SJ1: ESP32_C6_LIBRARY_7_JUMPER_SJ
SW_DN: 2025-10-22_07-23-44_LIBRARY_EVP-AKE31ASW_EVP-AKE3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; 2025-10-22_07-23-44_LIBRARY_SW_EVP-AKE31A_PAN
SW_ENT: 2025-10-22_07-23-44_LIBRARY_EVP-AKE31ASW_EVP-AKE3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; 2025-10-22_07-23-44_LIBRARY_SW_EVP-AKE31A_PAN
SW_UP: 2025-10-22_07-23-44_LIBRARY_EVP-AKE31ASW_EVP-AKE3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; 2025-10-22_07-23-44_LIBRARY_SW_EVP-AKE31A_PAN
TP_BAT_GND: HECTOR_WATCH_1_TPTP20R; HECTOR_WATCH_1_TP20R
TP_ON: HECTOR_WATCH_1_TPTP20R; HECTOR_WATCH_1_TP20R
TP_OP: HECTOR_WATCH_1_TPTP20R; HECTOR_WATCH_1_TP20R
TP_VBAT: HECTOR_WATCH_1_TPTP20R; HECTOR_WATCH_1_TP20R
U3: MAX17048G+T10; ESP32_C6_LIBRARY_SON50P200X200X80-9N

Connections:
3V3/1.7D: C34.2, DMG2305UX-7.2 (S), IC2.C2 (VDD), R5.2, R7.2, R8.2, R_PWR_EPD.2
ALERT/1.6C: U3.5 (!ALERT)
D+/1.5D: D3.4 (I/O2_2)
D-/1.5D: D3.6 (I/O1_2)
DN: D3.1 (I/O1_1), J4.A7 (DN1), J4.B7 (DN2)
DP: D3.3 (I/O2_1), J4.A6 (DP1), J4.B6 (DP2)
EPD_3V3: C1-EP-DR.1, DMG2305UX-7.3 (D), EPD_C5.2, J1.15, J1.16, L5.1
EPD_BUSY/1.5D: J1.9
EPD_CS/1.4C: J1.12
EPD_DC/1.5D: J1.11
EPD_RST/1.5D: J1.10
GDR: J1.2, Q3.1 (G), R2_EP_DR.2
GND: C1-EP-DR.2, C27.1, C29.1, C30.1, C31.1, C32.1, C34.1, C42.2, C43.2, D3.2 (GND), D4.1 (K), EPD_C1.1, EPD_C2.1, EPD_C5.1, EPD_C6.1, EPD_C7.1, EPD_C8.1, EPD_C9.1, EPD_C10.1, EPD_C11.1, EPD_C12.1, IC2.B1 (IN/TRIG), IC2.B3 (GND), J1.8, J1.17, J1.MP1, J1.MP2, J4.A1_B12 (GND), J4.A12_B1 (GND), J4.SH1 (SHIELD), J4.SH2 (SHIELD), J4.SH3 (SHIELD), J4.SH4 (SHIELD), R1_USB.1, R2_EP_DR.1, R2_USB.2, R_TYPE_SEL.1, SJ1.1, SW_DN.1, SW_ENT.1, SW_UP.1, TP_BAT_GND.TP, U3.1 (CTG), U3.4 (GND), U3.6 (QSTRT), U3.9 (EP); also elsewhere on the board
HAPTIC_EN/1.4C: IC2.A1 (EN)
MOSI/1.5B: J1.14
unnamed: C2-EP-DR.2, D5.2 (A), L5.2, Q3.3 (D)
unnamed: C2-EP-DR.1, D2.1 (K), D4.2 (A)
unnamed: EPD_C6.2, J1.18
unnamed: R1_EP_DR.1, R_TYPE_SEL.2, SJ1.2
unnamed: EPD_C2.2, J1.4
unnamed: EPD_C1.2, J1.5
unnamed: EPD_C7.2, J1.19
unnamed: EPD_C8.2, J1.20
unnamed: C32.2, IC2.A2 (REG)
unnamed: EPD_C10.2, J1.22
unnamed: J4.A5 (CC1), R1_USB.2
unnamed: EPD_C12.2, J1.24
unnamed: J4.B5 (CC2), R2_USB.1
OUT+: IC2.A3 (OUT+), TP_OP.TP
OUT-: IC2.C3 (OUT-), TP_ON.TP
P0.13/1.5D: C30.2, R5.1, SW_UP.2
P0.14/1.5D: C31.2, R8.1, SW_ENT.2
P1.01/1.6C: DMG2305UX-7.1 (G), R_PWR_EPD.1
P1.02/1.6C: C29.2, R7.1, SW_DN.2
PREVGH: D5.1 (K), EPD_C9.2, J1.21
PREVGL: D2.2 (A), EPD_C11.2, J1.23
RESE: J1.3, Q3.2 (S), R1_EP_DR.2
SCK/1.5B: J1.13
SCL/1.4C: IC2.C1 (SCL), U3.7 (SCL)
SDA/1.4C: IC2.B2 (SDA), U3.8 (SDA)
VBAT/1.2A: C27.2, TP_VBAT.TP, U3.2 (CELL), U3.3 (VDD)
VBUS/1.5D: C42.1, C43.1, D3.5 (VBUS), J4.A4_B9 (VBUS), J4.A9_B4 (VBUS)

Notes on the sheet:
E-Paper Drive Circuit
E-Paper Display Connector
Fuel Gauge
Buttons
Haptic Driver
USB C Connector & ESD Protection
E-Paper & Peripherals
drawn by:Petcu Robert
InkTime v6
04.29.2026 15:29

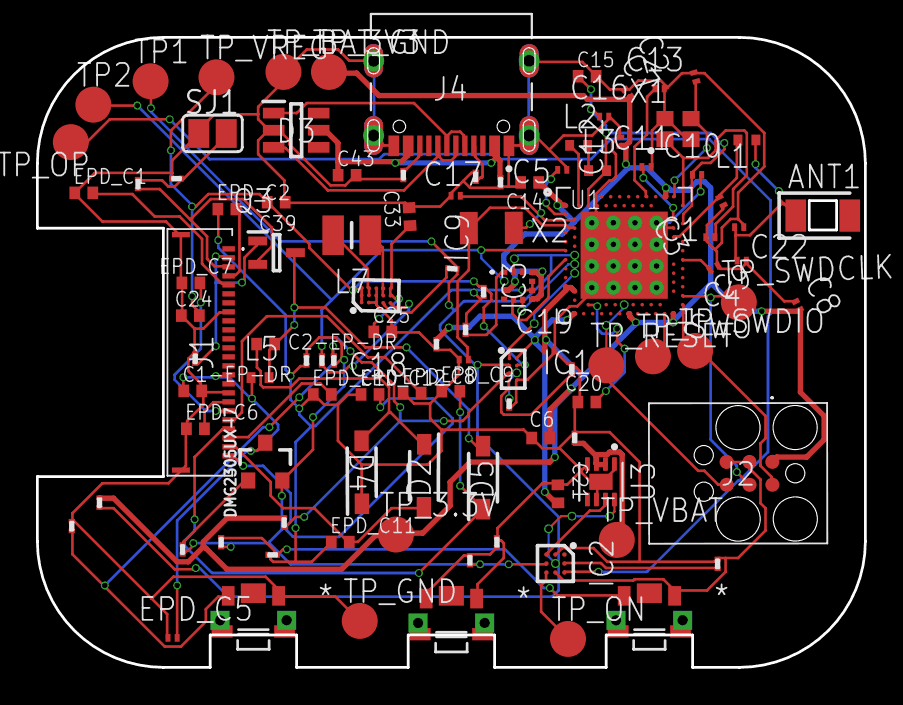
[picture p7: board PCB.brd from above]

Board: 2 copper layers, 46.0 x 35.0 mm, 105 parts (0 on the bottom side), 66 nets.

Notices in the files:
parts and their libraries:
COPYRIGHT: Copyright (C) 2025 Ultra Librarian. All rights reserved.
